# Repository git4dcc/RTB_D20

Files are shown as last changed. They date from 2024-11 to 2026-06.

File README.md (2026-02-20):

# RTB_D20




My Homebrew [D20](https://rtb4dcc.de/hardware/decoder/d20/) decoder is a double sided mobile decoder with NEM-651 connector. The decoder is designed to integrate into the [RTB](https://rtb4dcc.de/concept/) digital control infrastructure.

<details>
<summary>See also</summary>

- [RTB_D12 - custom](/../../../../git4dcc/RTB_D12) (Fleischmann V100)
- [RTB_D13 - custom](/../../../../git4dcc/RTB_D13) (Minitrix coach)
- [RTB_D15 - custom](/../../../../git4dcc/RTB_D15) (Minitrix V160)
- [RTB_D16 - NEM651](/../../../../git4dcc/RTB_D16)
- [RTB_D21 - Next18](/../../../../git4dcc/RTB_D21)
- [RTB_D22 - Plux16](/../../../../git4dcc/RTB_D22)
- [RTB_D23 - NEM652](/../../../../git4dcc/RTB_D23)

</details>

<details>
<summary>User Guides</summary>

- User Guide - DE
- [User Guide - EN](https://rtb4dcc.de/rtb_decoder_reference_en/)

</details>

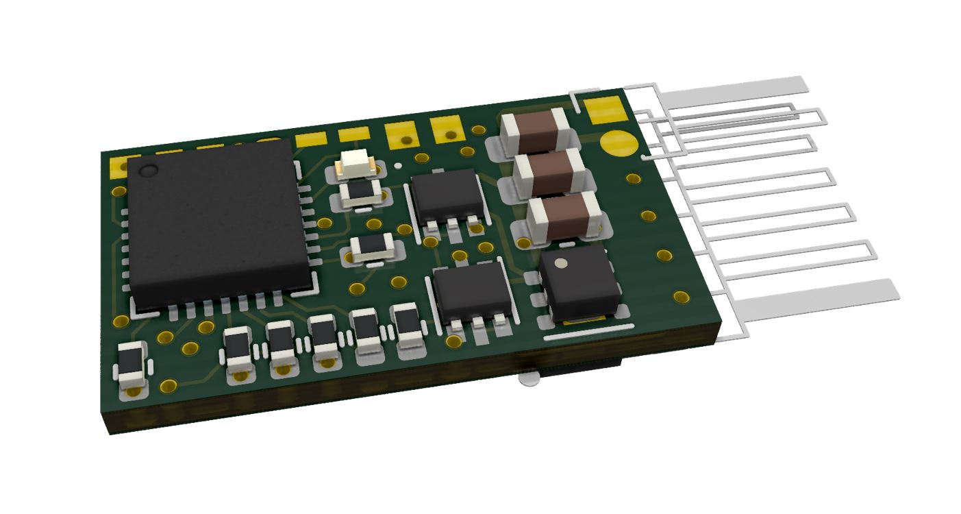
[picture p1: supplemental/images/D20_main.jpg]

<br>

The decoder has the following features,
- **NEM-651** connector
- **DCC**
  - DCC-A automatic logon
  - DCC-R protocol extension
  - Service Mode Programming
- **Railcom**
  - Channel 1/2
  - POM, xPOM
  - DYN: Speed, QoS, Track-voltage, Motor-current, AUX-current, Temp, Distance travelled
- Double sided
- Dimension: 14 x 8 mm
- 7-20V track voltage
- heartbeat LED
- adjustable max motor current (default 300mA)
- adjustable max AUX current (default 500mA)
- over temp protection
- Function output: LF/LR (dimmable, 1.4kHz) open drain
- Function output: AUX1/AUX2 (dimmable, 1.4kHz) open drain and logic level (3.3V)
- Function output: AUX3/AUX4 logic level (3.3V)
- optional external buffer capacitor (max. 1500uF)
- <10mA idle power consumption
- Firmware update over main tracks via DCC-R protocol

# Hardware
The current PCB layout uses SMD footprints with 0.5mm pitch, 0402 and 0201 parts. Reflow soldering is mandatory.

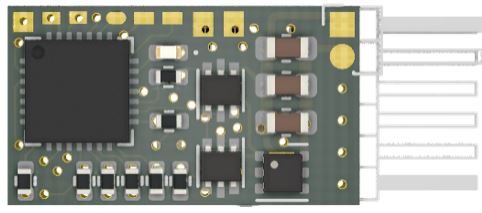
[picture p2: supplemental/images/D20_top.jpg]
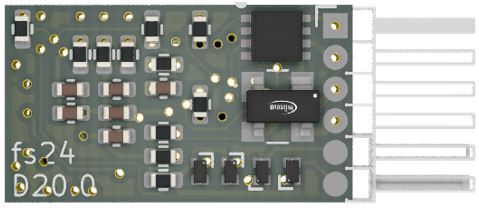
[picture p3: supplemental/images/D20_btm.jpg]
   

## PCB
- 6-layer PCB, FR4, 14 x 8 x 0.8mm (double sided)
- CPU: AVR64DD28
- Motor bridge: DRV8231
- Connector: NEM-651

## Kicad
[Schematic](doc/D20_schematic.pdf) | [Layout](doc/D20_layout.pdf) | [Gerber](gerber)

<details>
<summary>Dependency</summary>
<br>

:yellow_circle: Requires my Kicad project library [RTB_SamacSys](https://github.com/git4dcc/RTB_SamacSys) in the same directory tree.

</details>

## Firmware
Filename structure: { **pcb** }{ **code** }{ **version** }.hex

Example: **D20F0001**.hex

| | Description |
| --- | --- |
| **pcb** | Name of matching hardware (**D20**) |
| **code** | Type of code contained (**R**=rom, **B**=bootloader, **F**=flash, **U**=bld update, **P**=UPDI factory code) |
| **version** | Release version (**####**) |

[Firmware files](firmware)

## UPDI
The fuse settings as well as the P-code (D20Pxxxx.hex) has to be installed by using UPDI.<br>
Connecting the decoder via its track pins to a 5V(DC) power supply will boot its CPU. This way, its easy to program the fuses and flash.

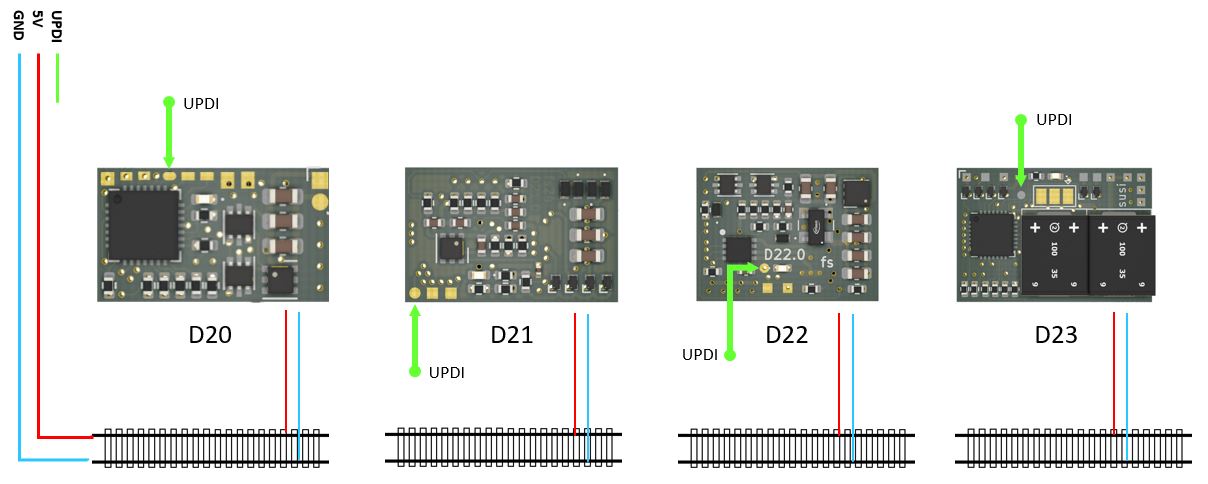
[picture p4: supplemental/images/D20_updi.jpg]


<details>
<summary>Details</summary>

| Fuse Setting | P-code Install |
| --- | --- |
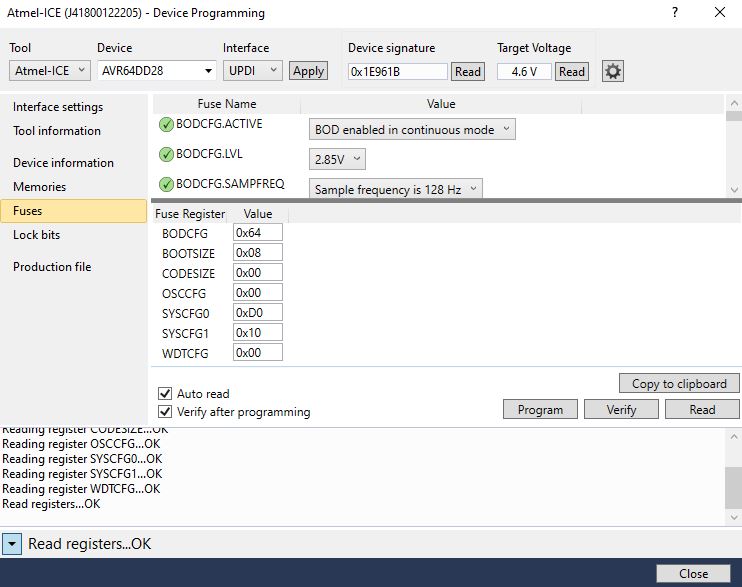
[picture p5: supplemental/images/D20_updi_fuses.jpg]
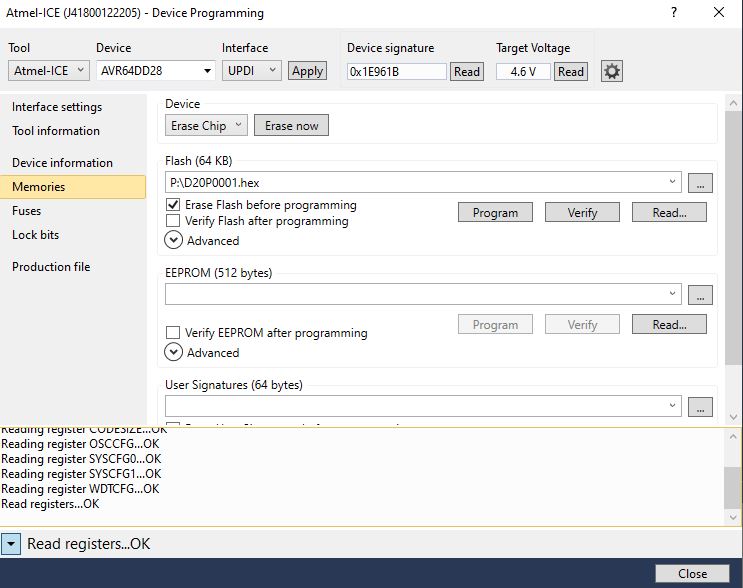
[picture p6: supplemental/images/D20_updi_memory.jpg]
|||

</details>

# Images
| top | bottom |
| --- | --- |
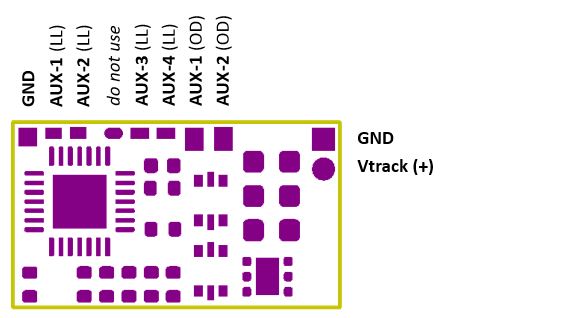
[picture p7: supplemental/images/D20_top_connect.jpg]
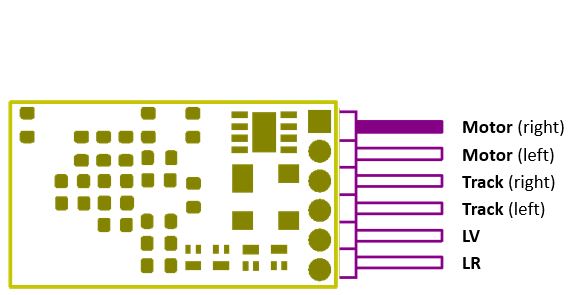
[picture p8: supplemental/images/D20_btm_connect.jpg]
|  |  |

# YouTube
Some YouTubes to see the D20 decoder in action.<br><br>
[](https://youtu.be/aH7pGpX5ZGo)
[](https://youtu.be/Ebl8b5DK1Gw)

This project is intended for hobby use only and is distributed in accordance with the Apache License 2.0 agreement.

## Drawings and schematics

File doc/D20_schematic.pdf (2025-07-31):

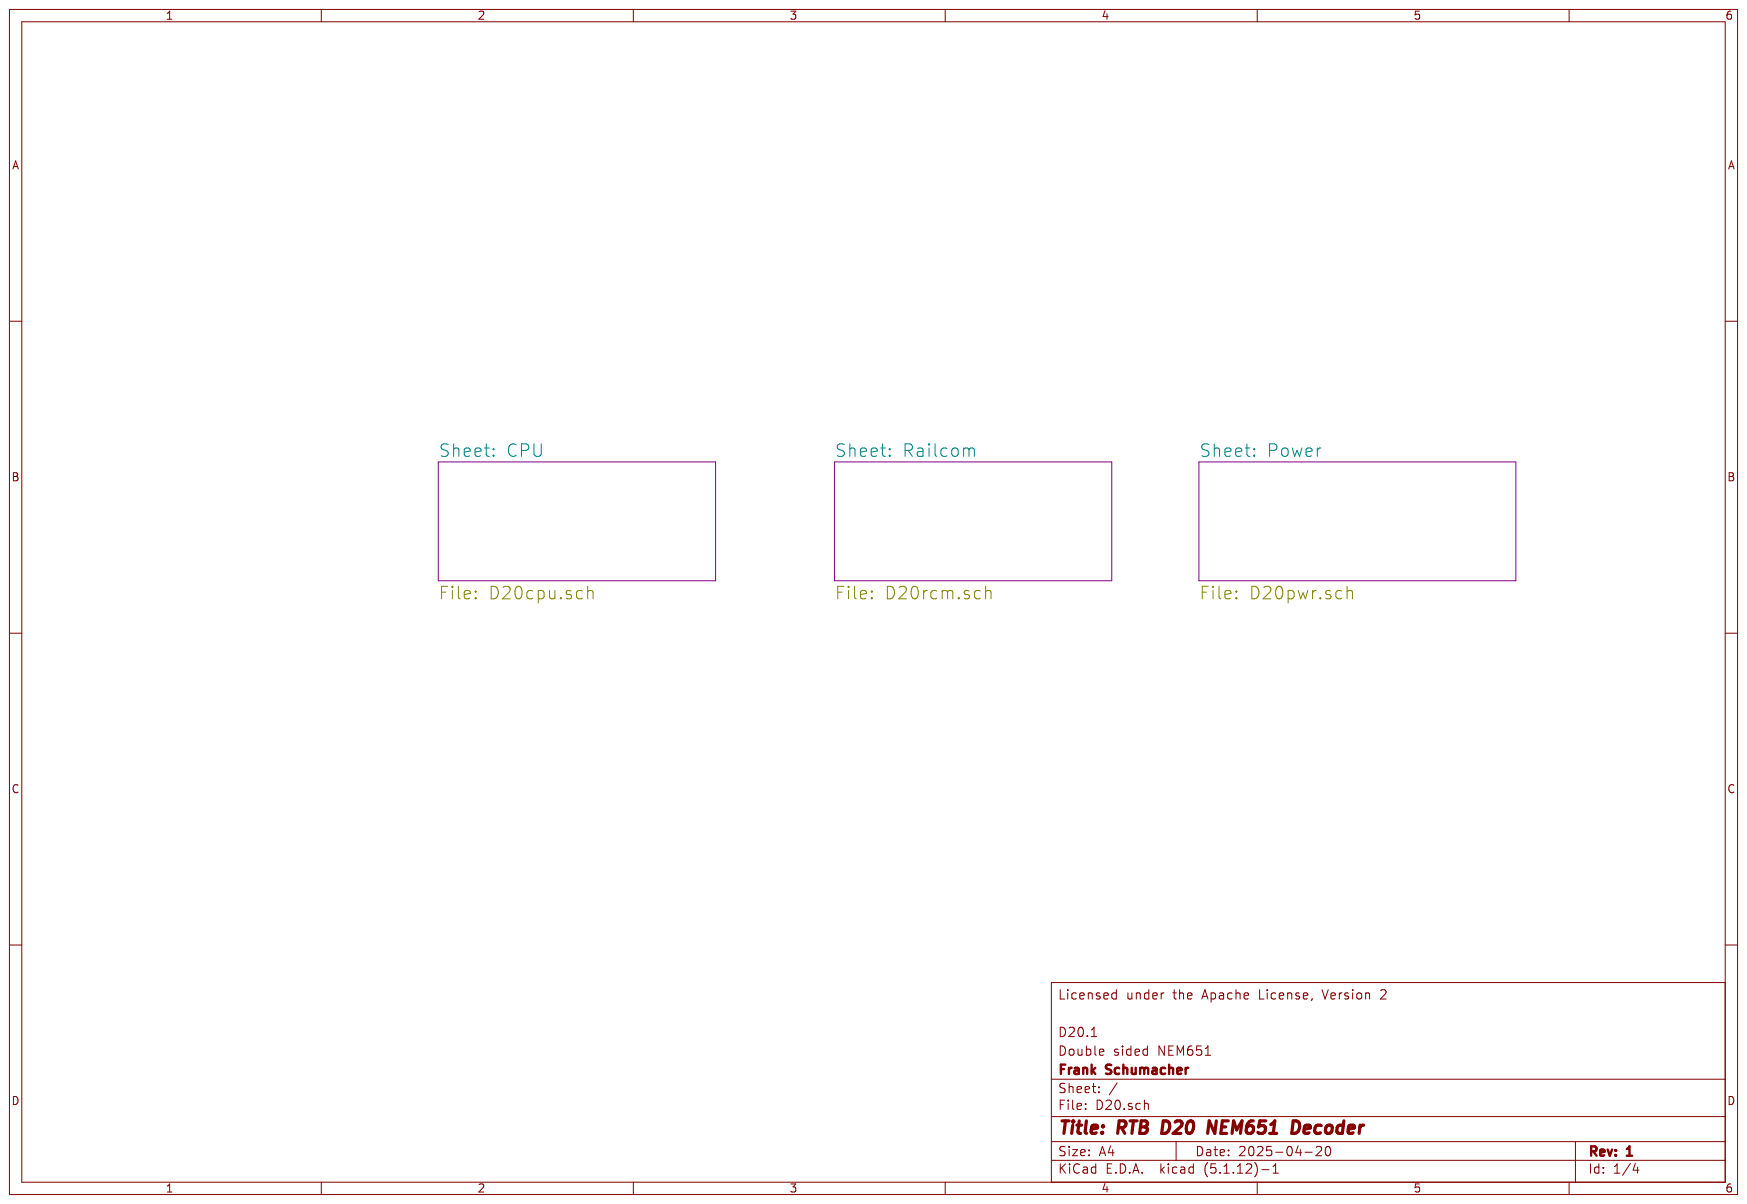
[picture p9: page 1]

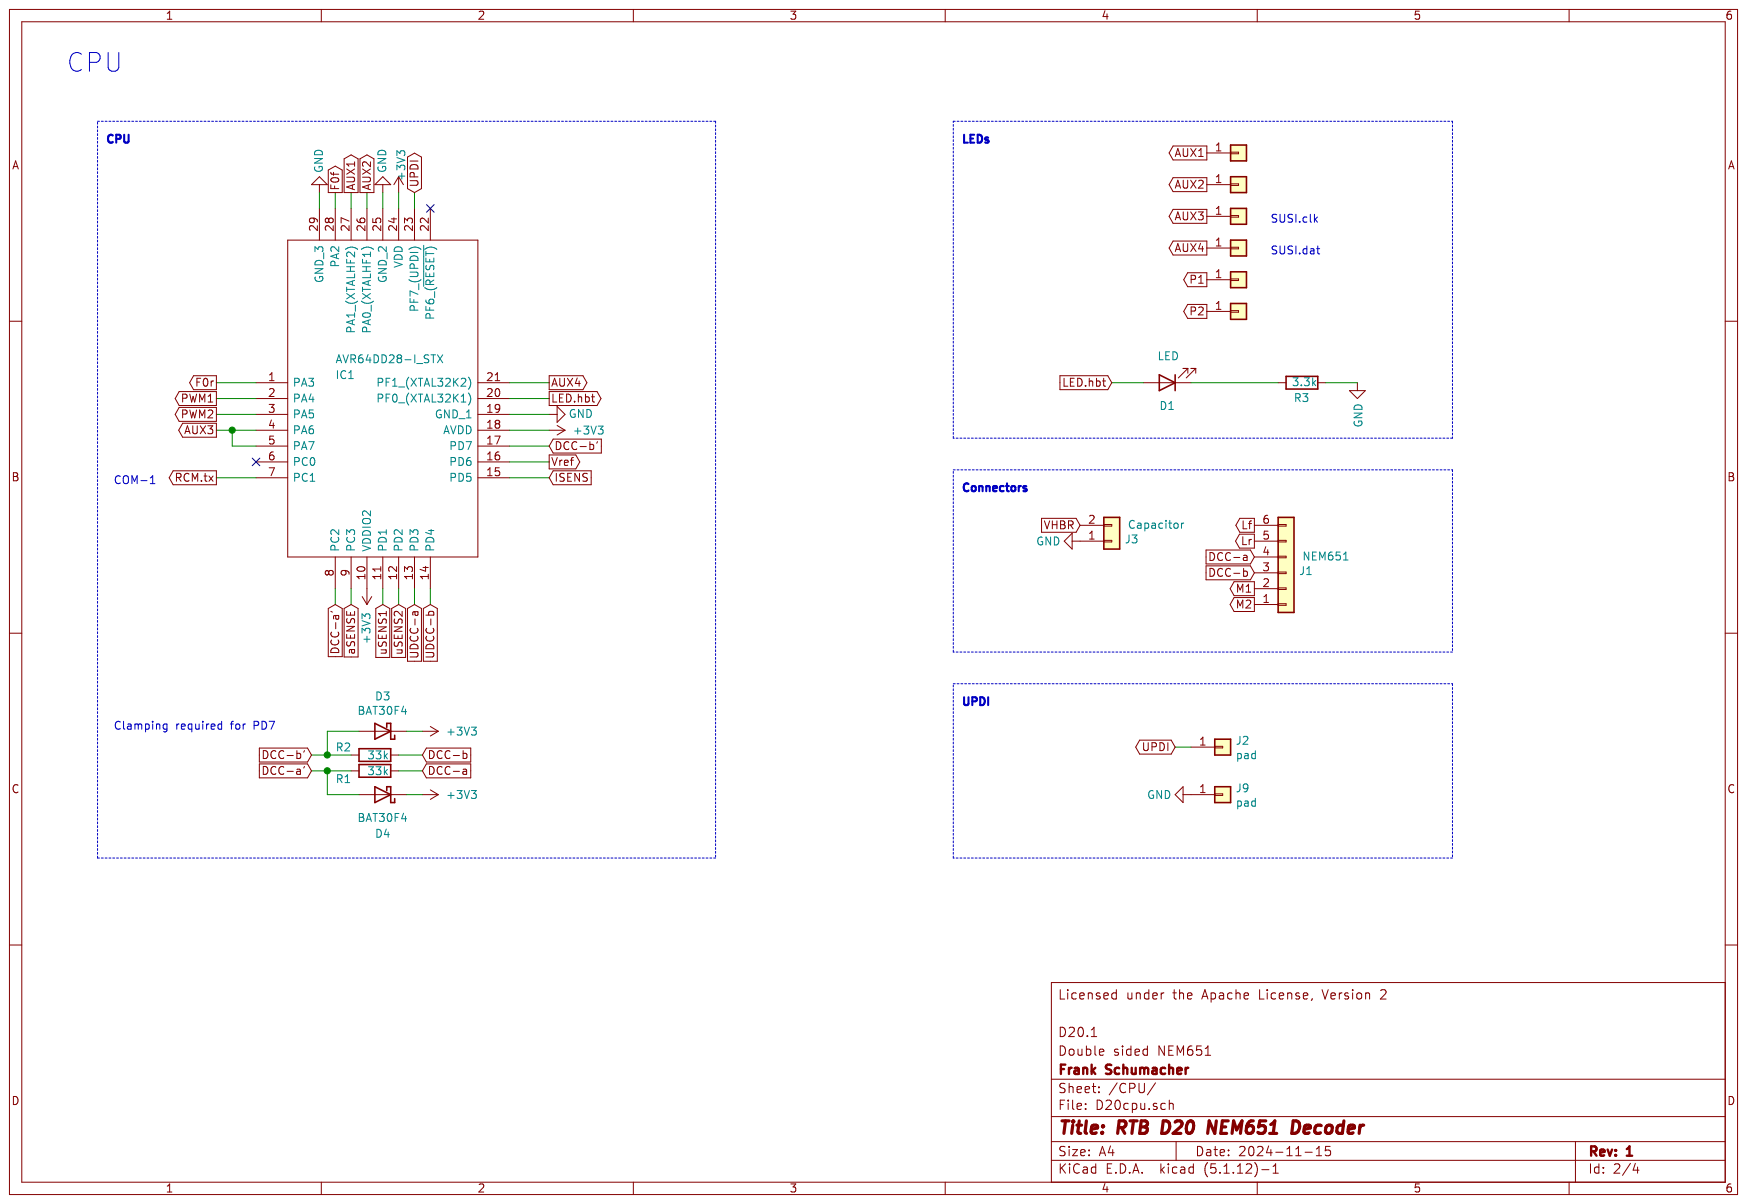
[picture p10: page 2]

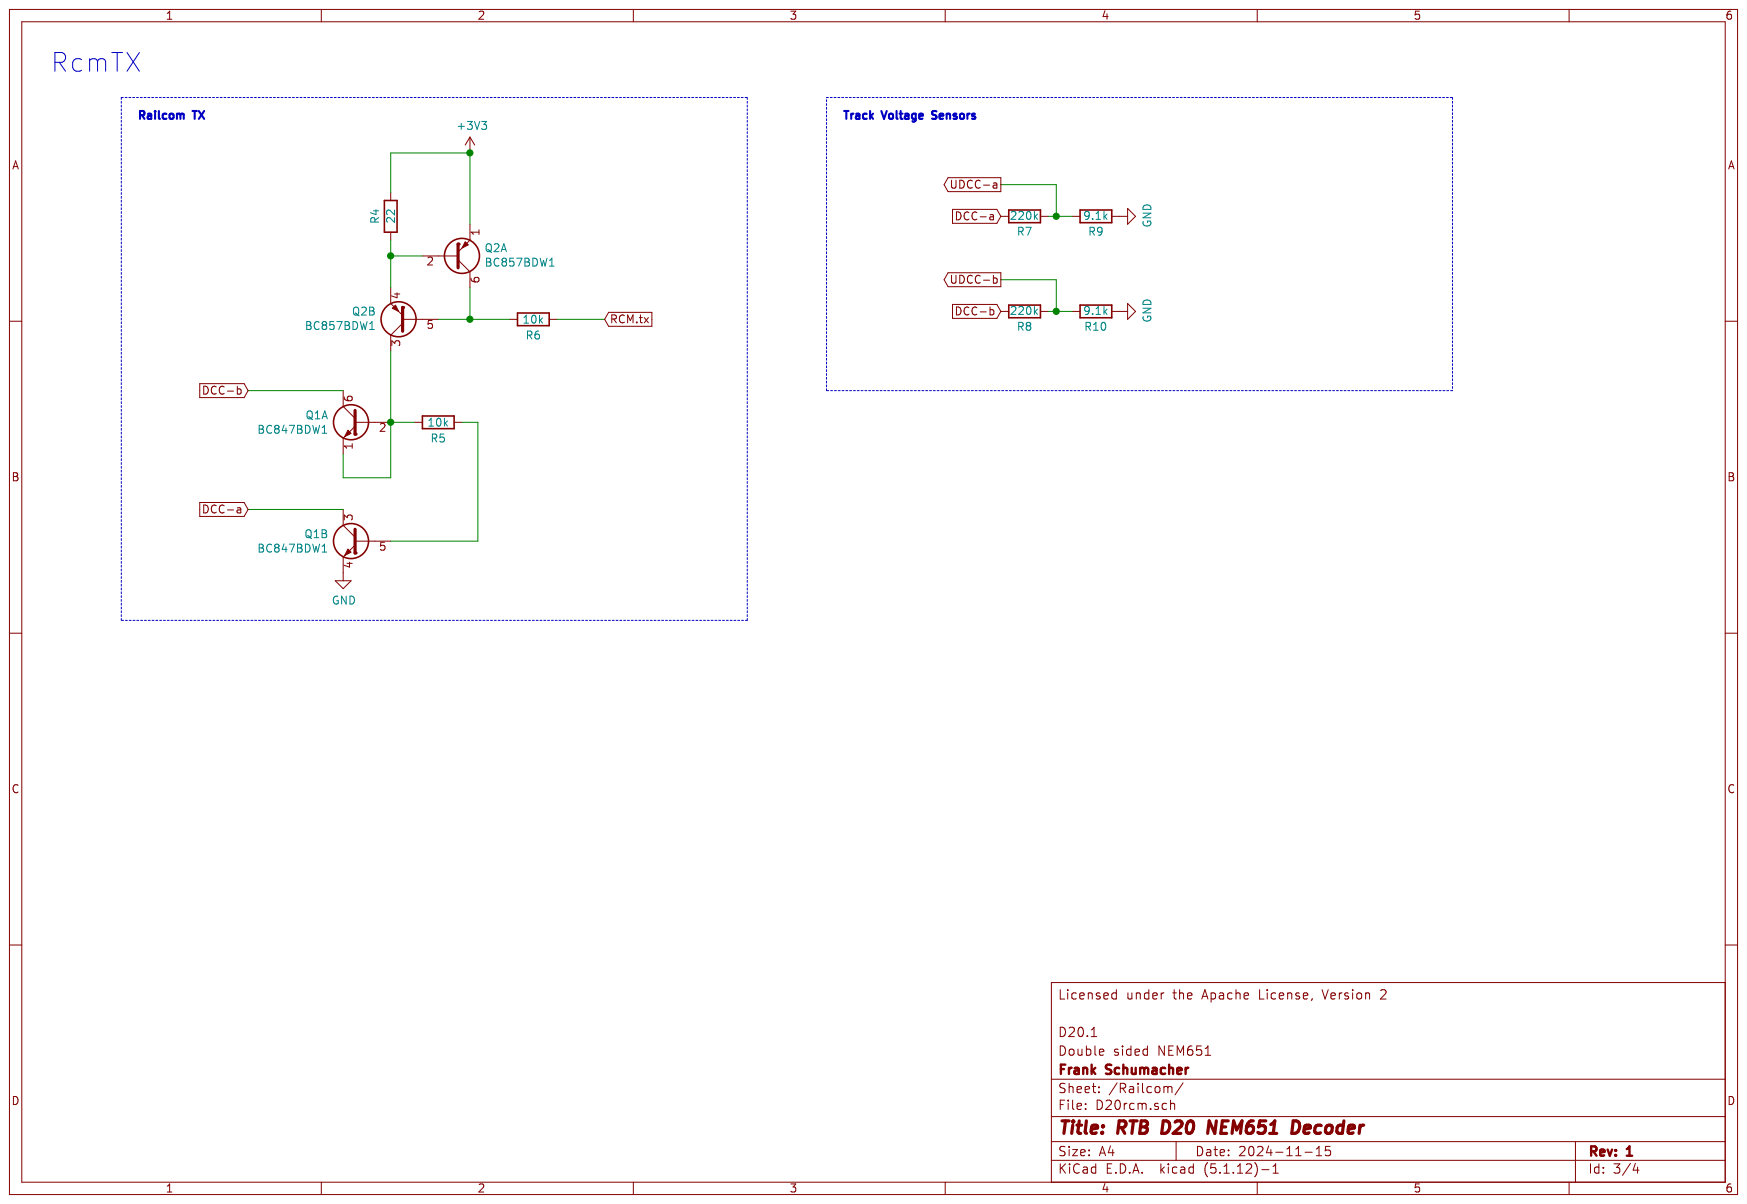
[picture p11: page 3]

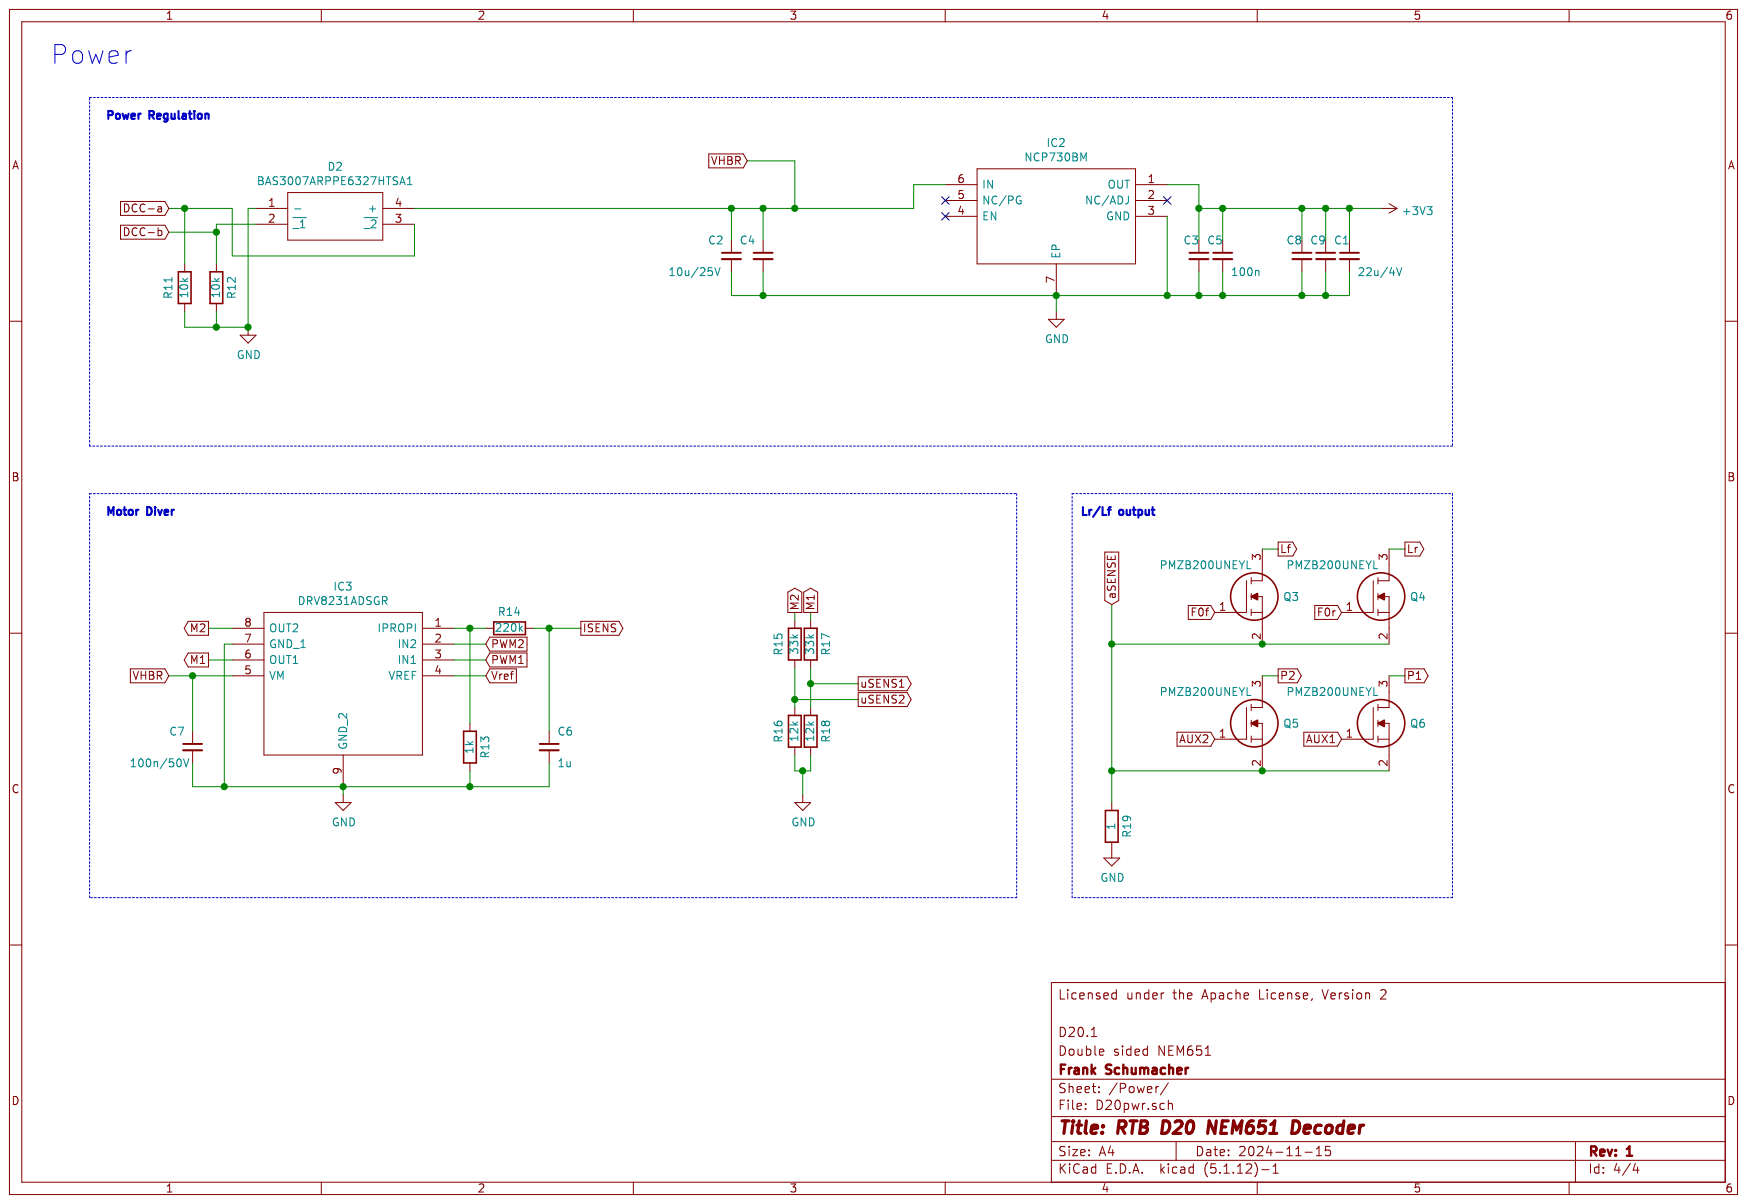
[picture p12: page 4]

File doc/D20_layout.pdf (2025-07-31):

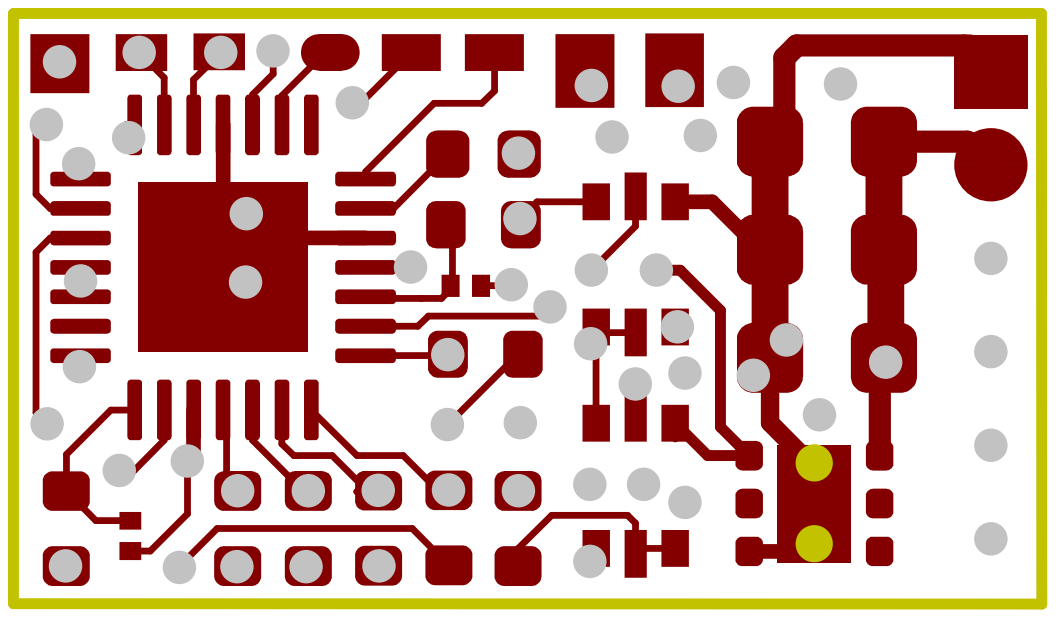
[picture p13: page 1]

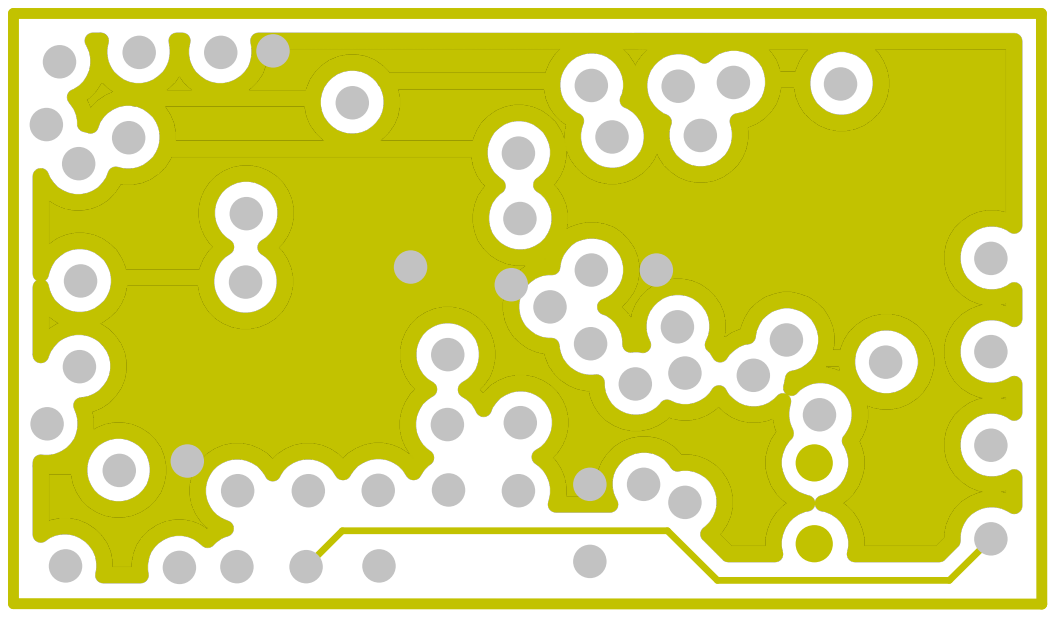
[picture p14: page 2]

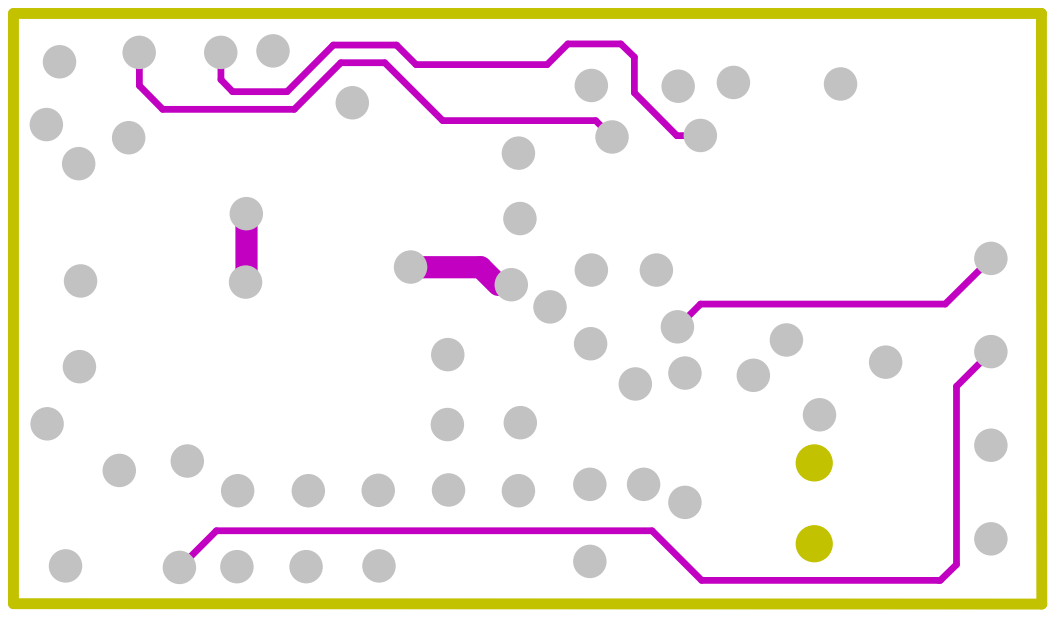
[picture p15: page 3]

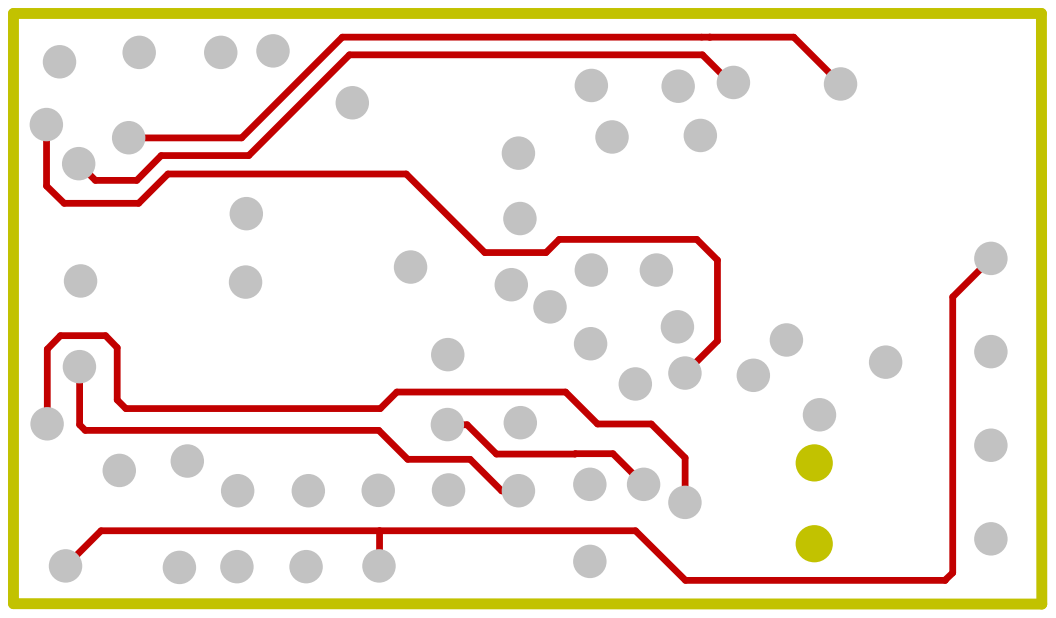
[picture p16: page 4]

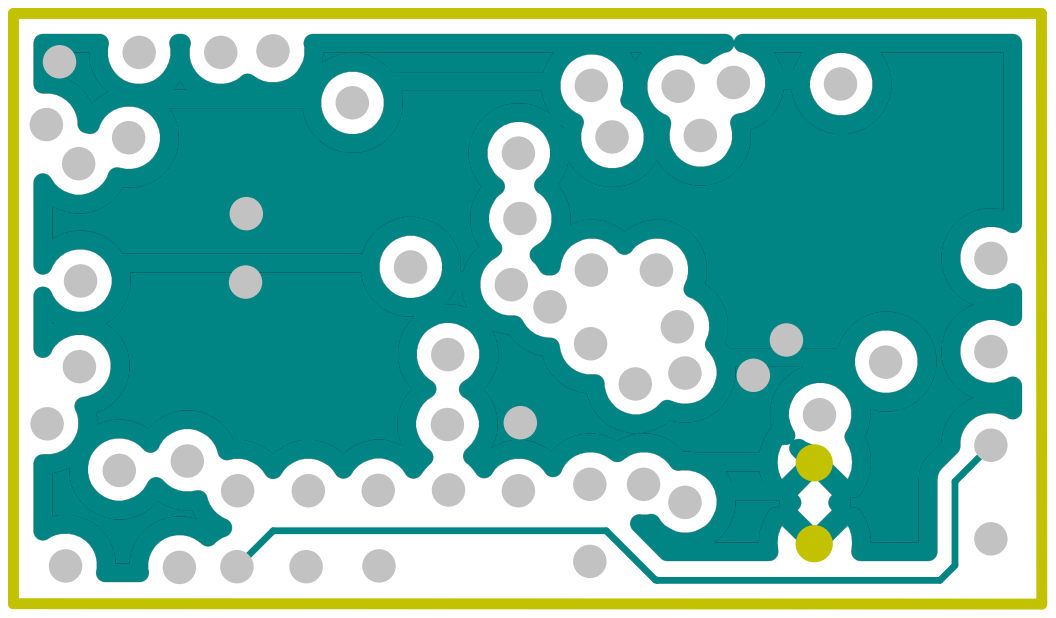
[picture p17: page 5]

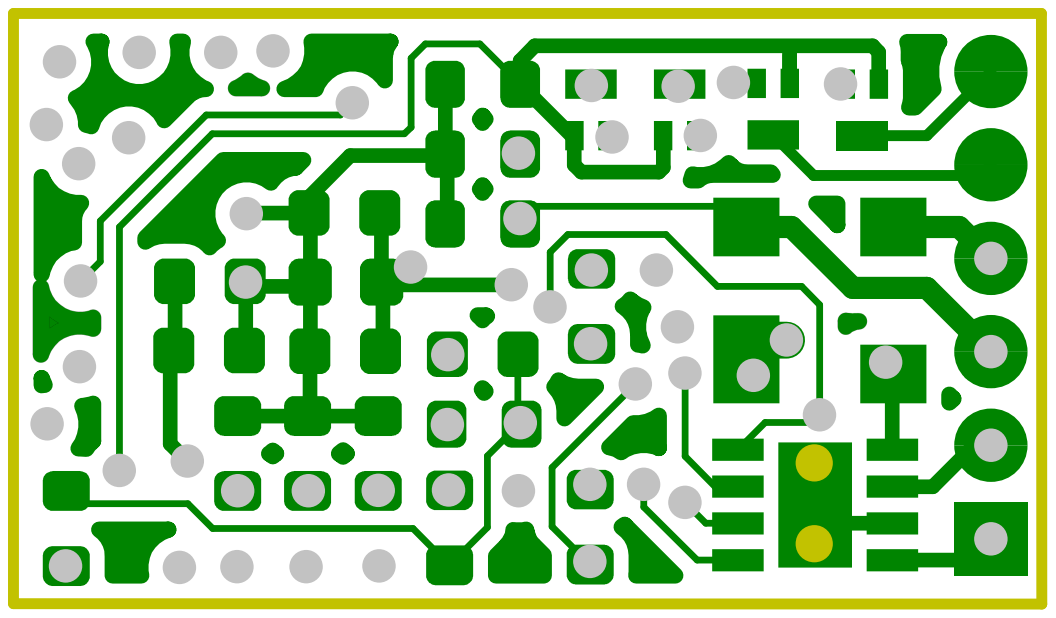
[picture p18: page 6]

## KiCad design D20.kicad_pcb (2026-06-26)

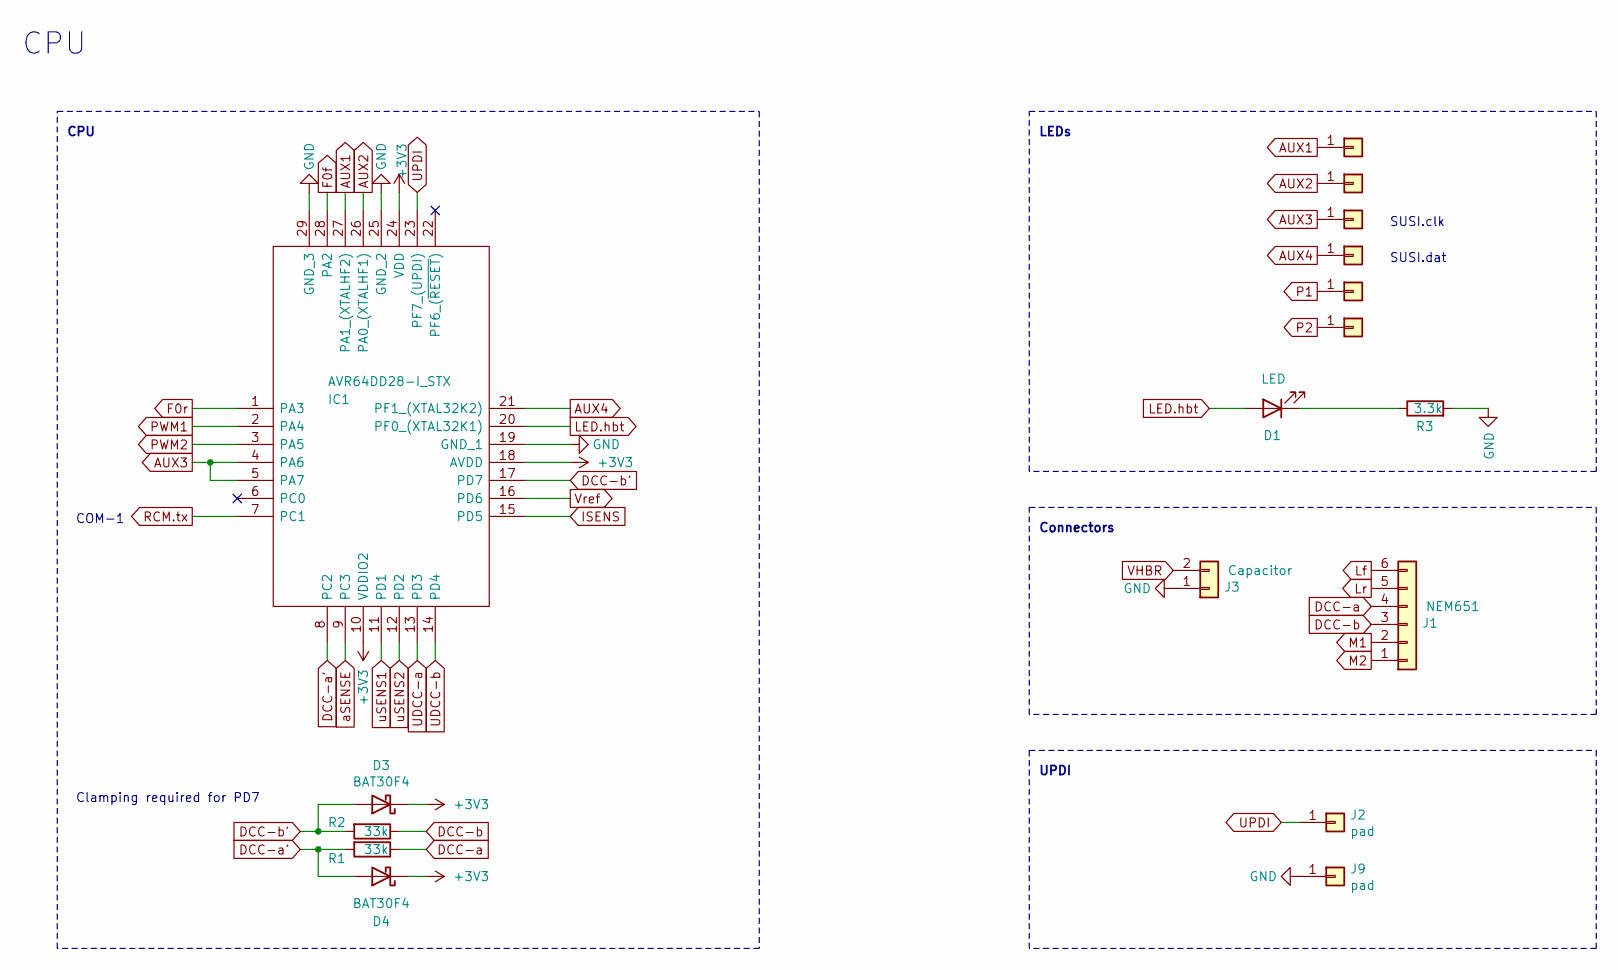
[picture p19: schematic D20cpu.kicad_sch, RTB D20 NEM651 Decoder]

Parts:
D1: LED; LED_0402_1005Metric
D3, D4: BAT30F4
IC1: AVR64DD28-I_STX; QFN-28-1EP_4x4mm_P0.4mm_EP2.3x2.3mm; Mouser Part Number 494-AVR64DD28-I/STX
J1: NEM651; PinHeader_1x06_P1.27mm_Horizontal
J2, J9: pad; DummyNet-Connector
J3: Capacitor; PinHeader_1x02_P1.27mm_Horizontal
J4, J5, J6, J7, J8, J10: Conn_01x01; DummyNet-Connector
R1, R2: 33k; R_0402_1005Metric
R3: 3.3k; R_0402_1005Metric

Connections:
+3V3: D3.1 (K), D4.1 (K), IC1.10 (VDDIO2), IC1.18 (AVDD), IC1.24 (VDD); also elsewhere on the board
AUX1: IC1.27 (PA1_(XTALHF2)), J4.1 (Pin_1_1); also elsewhere on the board
AUX2: IC1.26 (PA0_(XTALHF1)), J5.1 (Pin_1_1); also elsewhere on the board
AUX3: IC1.4 (PA6), IC1.5 (PA7), J8.1 (Pin_1_1)
AUX4: IC1.21 (PF1_(XTAL32K2)), J10.1 (Pin_1_1)
DCC-a: J1.4, R1.1; also elsewhere on the board
DCC-a': D4.2 (A), IC1.8 (PC2), R1.2
DCC-b: J1.3, R2.1; also elsewhere on the board
DCC-b': D3.2 (A), IC1.17 (PD7), R2.2
F0f: IC1.28 (PA2); also elsewhere on the board
F0r: IC1.1 (PA3); also elsewhere on the board
GND: IC1.19 (GND_1), IC1.25 (GND_2), IC1.29 (GND_3), J3.1, J9.1 (Pin_1_1), R3.2; also elsewhere on the board
ISENS: IC1.15 (PD5); also elsewhere on the board
LED.hbt: D1.2 (A), IC1.20 (PF0_(XTAL32K1))
Lf: J1.6; also elsewhere on the board
Lr: J1.5; also elsewhere on the board
M1: J1.2; also elsewhere on the board
M2: J1.1; also elsewhere on the board
unnamed: D1.1 (K), R3.1
P1: J6.1 (Pin_1_1); also elsewhere on the board
P2: J7.1 (Pin_1_1); also elsewhere on the board
PWM1: IC1.2 (PA4); also elsewhere on the board
PWM2: IC1.3 (PA5); also elsewhere on the board
RCM.tx: IC1.7 (PC1); also elsewhere on the board
UDCC-a: IC1.13 (PD3); also elsewhere on the board
UDCC-b: IC1.14 (PD4); also elsewhere on the board
UPDI: IC1.23 (PF7_(UPDI)), J2.1 (Pin_1_1)
VHBR: J3.2; also elsewhere on the board
Vref: IC1.16 (PD6); also elsewhere on the board
aSENSE: IC1.9 (PC3); also elsewhere on the board
uSENS1: IC1.11 (PD1); also elsewhere on the board
uSENS2: IC1.12 (PD2); also elsewhere on the board

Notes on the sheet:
SUSI.clk
LEDs
Clamping required for PD7
CPU
UPDI
SUSI.dat
COM-1
Connectors

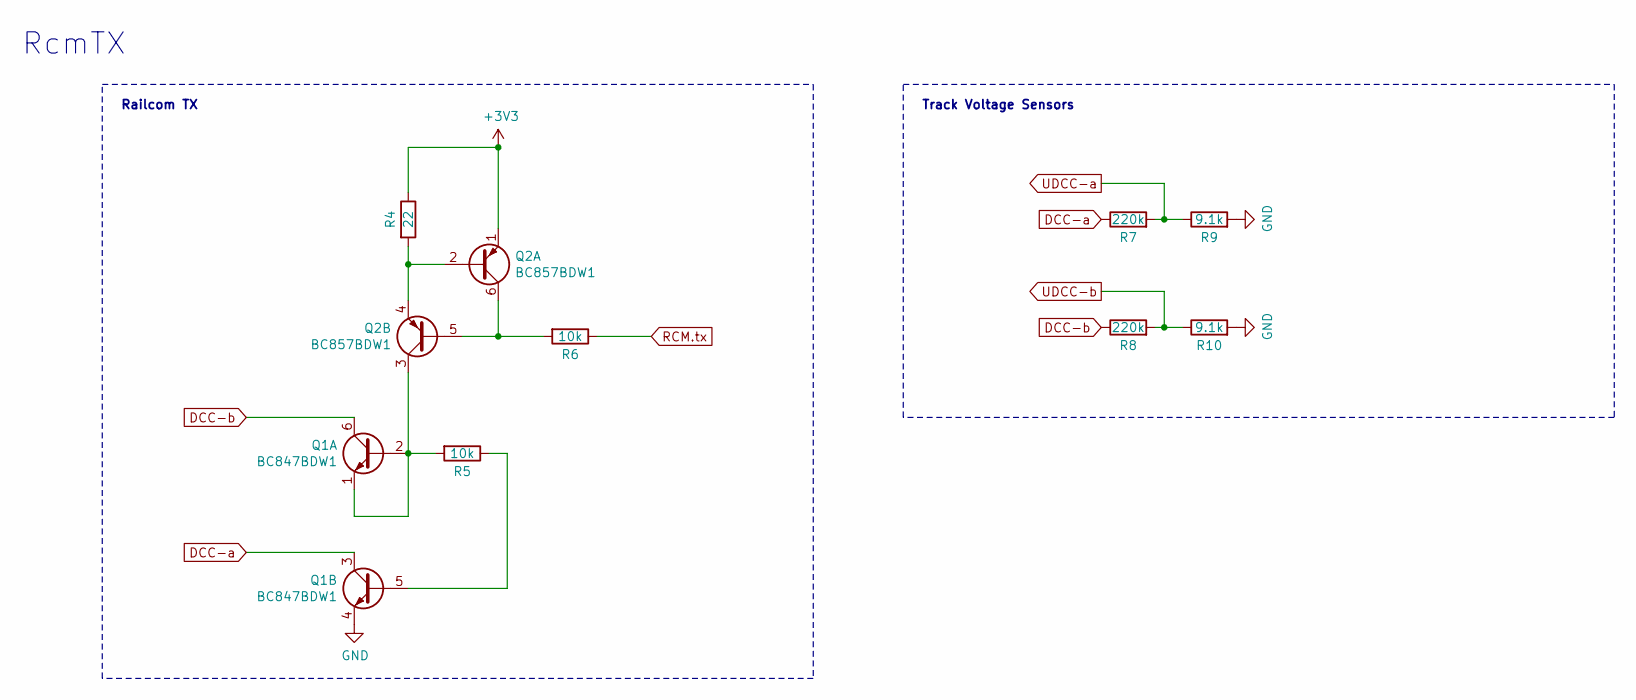
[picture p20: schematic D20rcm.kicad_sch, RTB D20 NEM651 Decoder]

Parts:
Q1: BC847BDW1; SOT-666
Q2: BC857BDW1; SOT-666
R4: 22; R_0402_1005Metric
R5, R6: 10k; R_0402_1005Metric
R7, R8: 220k; R_0402_1005Metric
R9, R10: 9.1k; R_0402_1005Metric

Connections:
+3V3: Q2.1 (E1), R4.1; also elsewhere on the board
DCC-a: Q1.3 (C2), R7.1; also elsewhere on the board
DCC-b: Q1.6 (C1), R8.1; also elsewhere on the board
GND: Q1.4 (E2), R9.2, R10.2; also elsewhere on the board
unnamed: Q1.1 (E1), Q1.2 (B1), Q2.3 (C2), R5.2
unnamed: Q1.5 (B2), R5.1
unnamed: Q2.2 (B1), Q2.4 (E2), R4.2
unnamed: Q2.5 (B2), Q2.6 (C1), R6.2
RCM.tx: R6.1; also elsewhere on the board
UDCC-a: R7.2, R9.1; also elsewhere on the board
UDCC-b: R8.2, R10.1; also elsewhere on the board

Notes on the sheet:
Track Voltage Sensors
RcmTX
Railcom TX

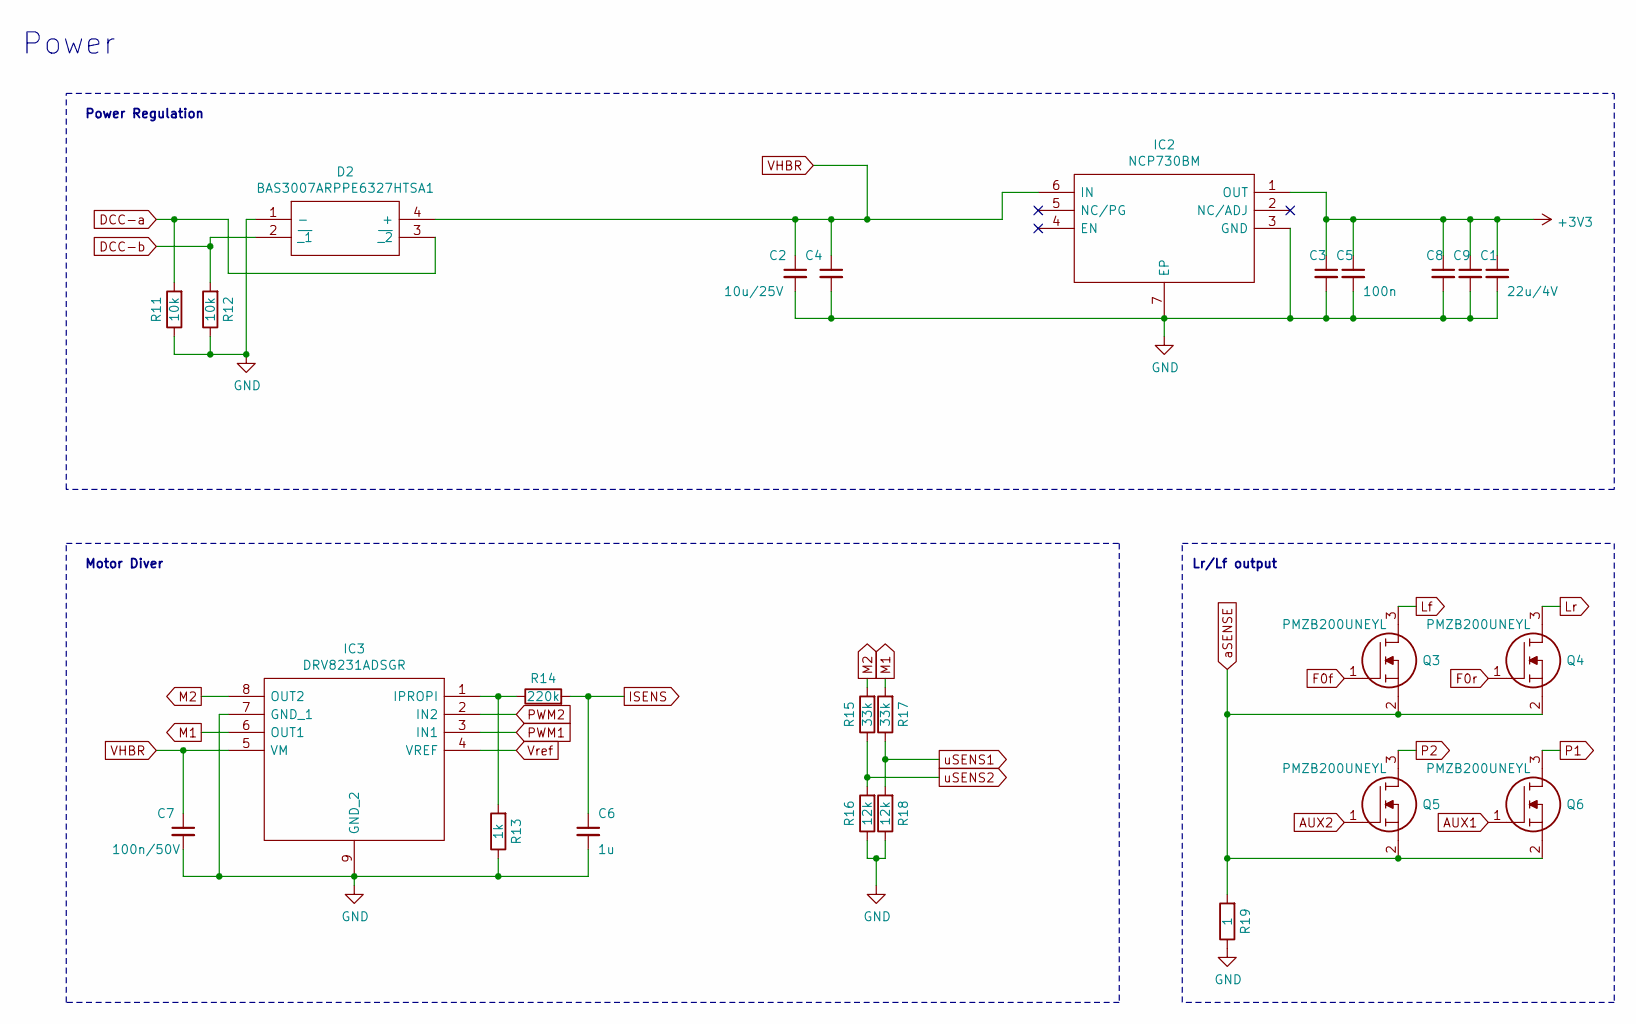
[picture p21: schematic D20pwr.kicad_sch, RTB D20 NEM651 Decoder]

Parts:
C1: 22u/4V; C_0402_1005Metric
C2: 10u/25V; C_0603_1608Metric
C3, C5: 100n; C_0402_1005Metric
C4: 22u/25V; C_0603_1608Metric
C6: 1u; C_0402_1005Metric
C7: 100n/50V; C_0603_1608Metric
C8, C9: 22u/6V; C_0402_1005Metric
D2: BAS3007ARPPE6327HTSA1; BF998215; Mouser Part Number 726-BAS3007A-RPPE6
IC2: NCP730BM; WSON-6-1EP_2x2mm_P0.65mm_EP1x1.6mm_ThermalVias; Mouser Part Number 863-NCP730BMT330TBG
IC3: DRV8231ADSGR; SON50P200X200X80-9N; Mouser Part Number 595-DRV8231ADSGR
Q3, Q4, Q5, Q6: PMZB200UNEYL; Diodes_DFN1006-3; LCSC Part # C547292
R11, R12: 10k; R_0402_1005Metric
R13: 1k; R_0402_1005Metric
R14: 220k; R_0402_1005Metric
R15, R17: 33k; R_0402_1005Metric
R16, R18: 12k; R_0402_1005Metric
R19: 1; R_0402_1005Metric

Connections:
+3V3: C1.1, C3.1, C5.1, C8.1, C9.1, IC2.1 (OUT); also elsewhere on the board
AUX1: Q6.1; also elsewhere on the board
AUX2: Q5.1; also elsewhere on the board
DCC-a: D2.3 (~_2), R11.2; also elsewhere on the board
DCC-b: D2.2 (~_1), R12.2; also elsewhere on the board
F0f: Q3.1; also elsewhere on the board
F0r: Q4.1; also elsewhere on the board
GND: C1.2, C2.2, C3.2, C4.2, C5.2, C6.2, C7.2, C8.2, C9.2, D2.1 (-), IC2.3 (GND), IC2.7 (EP), IC3.7 (GND_1), IC3.9 (GND_2), R11.1, R12.1, R13.1, R16.1, R18.1, R19.1; also elsewhere on the board
ISENS: C6.1, R14.2; also elsewhere on the board
Lf: Q3.3; also elsewhere on the board
Lr: Q4.3; also elsewhere on the board
M1: IC3.6 (OUT1), R17.2; also elsewhere on the board
M2: IC3.8 (OUT2), R15.2; also elsewhere on the board
unnamed: IC3.1 (IPROPI), R13.2, R14.1
P1: Q6.3; also elsewhere on the board
P2: Q5.3; also elsewhere on the board
PWM1: IC3.3 (IN1); also elsewhere on the board
PWM2: IC3.2 (IN2); also elsewhere on the board
VHBR: C2.1, C4.1, C7.1, D2.4 (+), IC2.6 (IN), IC3.5 (VM); also elsewhere on the board
Vref: IC3.4 (VREF); also elsewhere on the board
aSENSE: Q3.2, Q4.2, Q5.2, Q6.2, R19.2; also elsewhere on the board
uSENS1: R17.1, R18.2; also elsewhere on the board
uSENS2: R15.1, R16.2; also elsewhere on the board

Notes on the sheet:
Lr/Lf output
Motor Diver
Power Regulation
Power

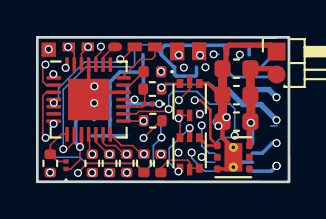
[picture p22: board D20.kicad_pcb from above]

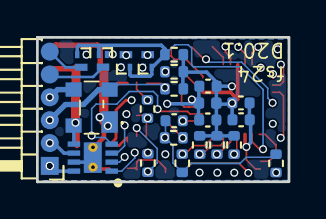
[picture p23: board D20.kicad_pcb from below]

Board: 6 copper layers, 14.0 x 8.0 mm, 51 parts (24 on the bottom side), 37 nets.

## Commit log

2024-11-13 add: clamping diode
    [D20.kicad_pcb, D20.sch, D20cpu.sch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]
2024-11-15 mod: documentation
    [D20.kicad_pcb, D20.sch, D20cpu.sch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]
2025-03-22 add: decoder lock
    [D20.kicad_pcb, D20cpu.sch]
2025-07-31 add: fuses
    [D20.kicad_pcb, D20.sch, D20pwr.sch]
2025-08-05 mod: led automation
2026-06-26 updated Kicad version
    [D20.kicad_pcb, D20.kicad_sch, D20cpu.kicad_sch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]

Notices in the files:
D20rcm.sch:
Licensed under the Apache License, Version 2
